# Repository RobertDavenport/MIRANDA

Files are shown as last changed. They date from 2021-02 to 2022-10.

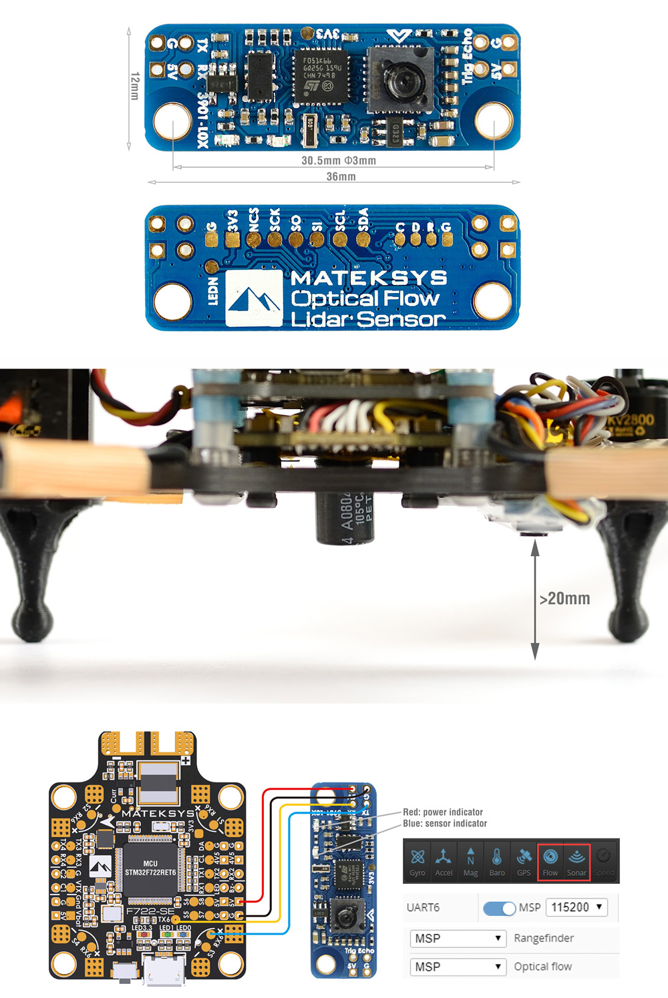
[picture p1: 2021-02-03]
project reference documents/parts/3901-L0X/3901-L0X.jpg

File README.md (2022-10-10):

# Robert-and-the-Davenports-Senior-Project

A set of wearable assistance devices which includes LIDAR sensors and one or more video cameras on glasses frames
and modular combinable haptic feedback devices. The device is capable of continually mapping a user’s environment in
relation to the user as they move and look around. The device also leverages artificial intelligence to take visual input
data from the onboard cameras to classify attributes. Processed data is relayed via audio and haptic cues to a user to allow
more situational awareness with the surrounding world. This set of devices is a novelty through the expanded
functionality of obstacle and object detection and recognition, in combination with haptic feedback.

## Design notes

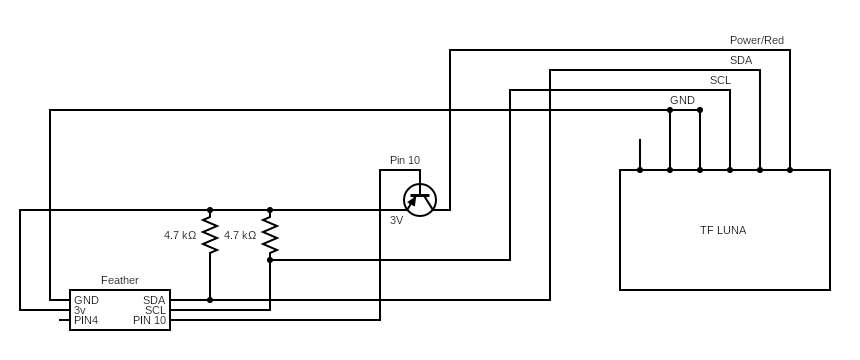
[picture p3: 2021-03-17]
project reference documents/FeatherTFLunaCircuitDiagram.png

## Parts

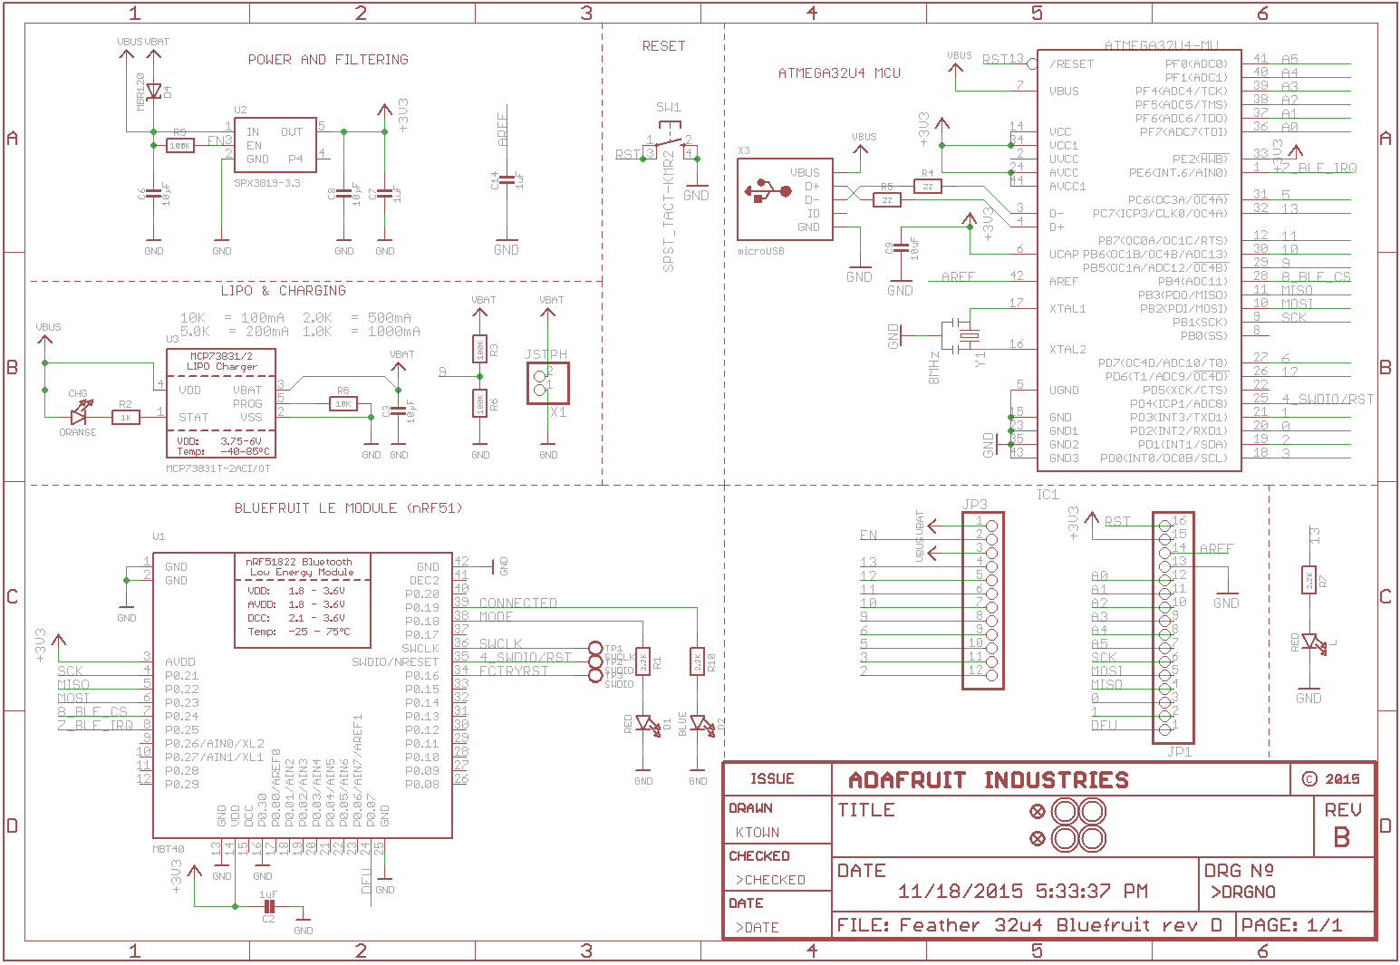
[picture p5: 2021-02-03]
project reference documents/parts/ADA2829/adafruit_products_schem.png

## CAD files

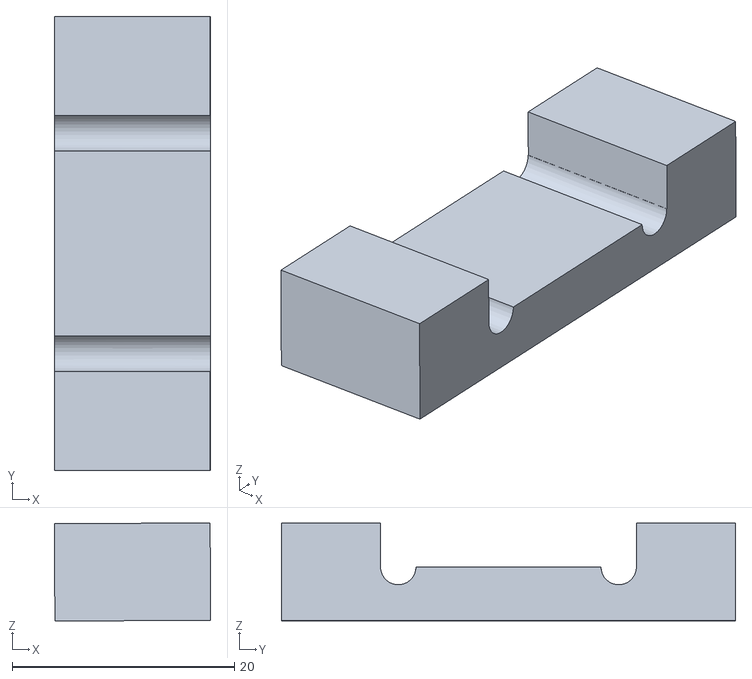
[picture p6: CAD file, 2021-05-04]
3d Printing Files/wristand pieces/wristband_pieces_-_motor_mount_x6 (1).stl
14.0 x 40.9 x 8.81

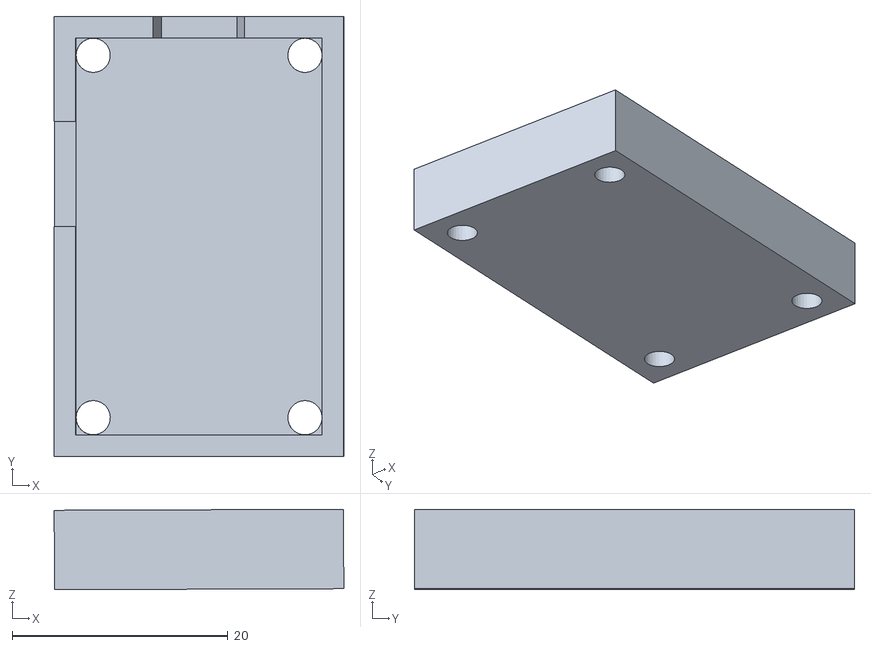
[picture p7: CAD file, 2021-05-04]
3d Printing Files/wristand pieces/wristband_pieces_v19_-_breakout_board_mount (1).stl
26.9 x 40.8 x 7.46

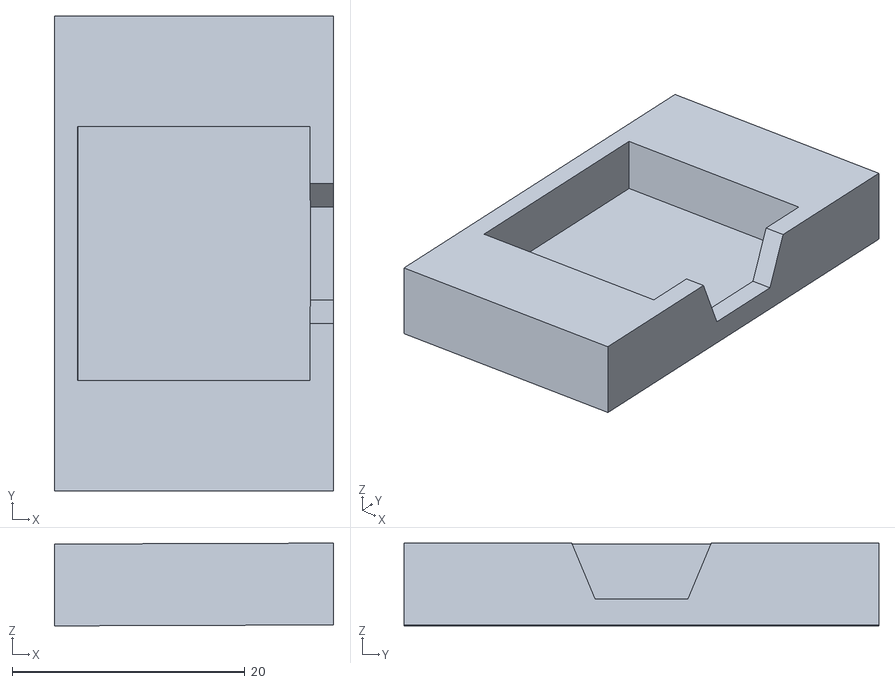
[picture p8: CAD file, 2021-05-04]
3d Printing Files/wristand pieces/wristband_pieces_-_switch_mount.stl
24.0 x 40.9 x 7.12

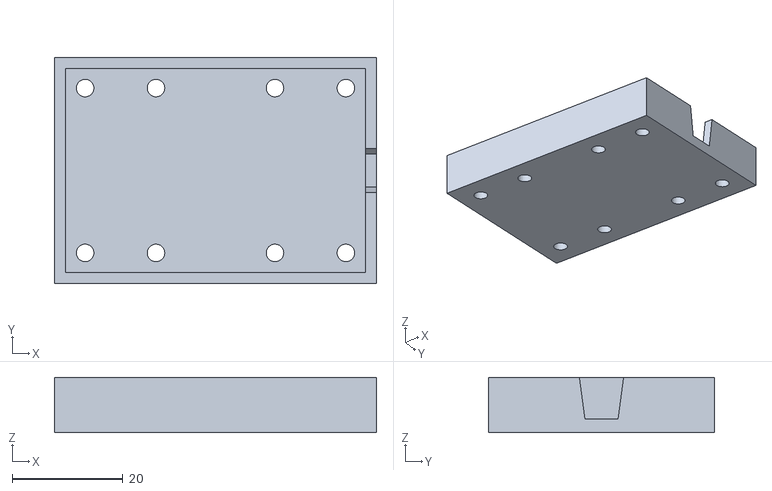
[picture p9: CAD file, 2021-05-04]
3d Printing Files/wristand pieces/wristband_pieces_v18_-_esp_battery_mount.stl
58.2 x 40.9 x 10.0

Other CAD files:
3d Printing Files/left bracket main.dwg
3d Printing Files/Base Mount/sensor plate.dwg
3d Printing Files/Base Mount/snap base.dwg
3d Printing Files/Base Mount/bracket base.dwg

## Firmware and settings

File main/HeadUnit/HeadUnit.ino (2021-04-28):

#include <math.h>
#include <I2Cdev.h>
#include <TFLI2C.h>
#include <MPU6050.h>
#include <Wire.h>
#include <Adafruit_MPU6050.h>
#include <Adafruit_Sensor.h>
#include <AsyncUDP.h>
#include <WiFi.h>
#include <String.h>
#include <sstream>

/* Determines if accelermeter will be used
   to account for movement when mapping the
   environment. */
#define MAP_AREA_WITHOUT_MOVEMENT

// Settings for area mapping structure
#define DPI 6
#define RADIAL_SEGMENTS 60
#define EMPTY -1

// Indices for sensor values
#define GYRO_X 0
#define GYRO_Y 1
#define GYRO_Z 2
#define ACCL_X 0
#define ACCL_Y 1
#define ACCL_Z 2

// Constants
#define ACCL_X_OFFSET 1.02
#define ACCL_Y_OFFSET 0.0005
#define ACCL_Z_OFFSET 0.155
#define NUM_LIDAR 3
#define NUM_HAPTICS 5
#define HAPTIC_CONTROL_LEVELS 8

/* Number of degrees in a cone that each haptic
   motor will be mapped to. */
#define DPH 15
#define MAX_DIST 100.0
#define MIN_DIST 0.0
#define MAX_READABLE_DIST 450.0
#define MIN_READABLE_DIST 0.0

// Math macros and definitions
#define PI 3.14159265
#define radians(d) (d*0.0174533)
#define degrees(r) (r*57.2958)
#define nearestK(n,k) (int)round(n/(float)k)
#define normalize(n) (((float)n-MIN_READABLE_DIST)/(MAX_READABLE_DIST - MIN_READABLE_DIST))*(MAX_DIST-MIN_DIST)+MIN_DIST;

// Data structures for area mapping and haptic control.
struct Sensors {
  float lidar[NUM_LIDAR];
  float accel[3];
  float gyro[3] = {0,0,0};
  bool lock = false;
};
struct AreaMap {
  float angles[RADIAL_SEGMENTS];
  float distances[RADIAL_SEGMENTS];
  bool lock = false;
};
struct HapticCommand {
  char hapticsArr[NUM_HAPTICS+2] = "hhhhh\0";
  char *haptics = hapticsArr;
  bool lock;
};

const uint8_t lidarAddresses[3] = {0x10, 0x20, 0x21};
const float lidarAngles[NUM_LIDAR] = {-15, 0, 15};
const float LIDAR_WIDTH = 30;
const float gyroOffset[3] = {0.0035025, 0.0025, 0.0019};
const float hapticOutputAngles[NUM_HAPTICS] = {-30, -15, 0, 15, 30};

float gyro[3];

// Definitions for haptic control intensity-to-distance mappings
const char HAPTIC_MAPPINGS_CHAR[HAPTIC_CONTROL_LEVELS] = {'a','b','c','d','e','f','g','h'};
const float HAPTIC_MAPPINGS_DIST[HAPTIC_CONTROL_LEVELS][2] = {{0,10},
                                                        {10,15},
                                                        {15,20},
                                                        {20,25},
                                                        {25,30},
                                                        {35,40},
                                                        {40,45},
                                                        {45,MAX_DIST+1}};

struct AreaMap areaMap; // Perm. struct for storing mapped area.
struct AreaMap tempMap; // Temp. struct for updating mapped area.
struct Sensors sensors; // Stores the rt-database of sensor values.
struct HapticCommand command; // Stores most recent haptic command.

// Wifi Connection Setup
const char *my_ssid = "esp32_ssid";
const char *password = "password";
int PORT = 1234;

unsigned long prevTime = 0;

Adafruit_MPU6050 mpu;
TFLI2C tfli2c;
AsyncUDP udp;

// Core-assigned task handles
TaskHandle_t AreaMappingTask;
TaskHandle_t ControlTask;

void setup() {
  Serial.begin(115200);  
  Wire.begin();
  mpu.begin();
  mpu.setGyroRange(MPU6050_RANGE_500_DEG);
  mpu.setFilterBandwidth(MPU6050_BAND_21_HZ);

  // Setup Wifi
  WiFi.mode(WIFI_AP);
  WiFi.softAP(my_ssid, password);

  // Control (networking and sensor reading) performed on core 0
  xTaskCreatePinnedToCore(
              control,        // Function
              "Control",      // Name
              16384,          // Stack size
              NULL,           // Parameters
              2,              // Priority
              &ControlTask,   // TaskHandle
              0);             // Core No.

  
  // Area mapping performed on core 1
  
  xTaskCreatePinnedToCore(
              areaMapping,      // Function
              "AreaMapping",    // Name
              16384,            // Stack size
              NULL,             // Parameters
              2,                // Priority
              &AreaMappingTask, // TaskHandle
              1);               // Core No.
  
  prevTime = millis();
  delay(1000);
}

void loop() {
}

void control( void * params ) {
  while(true) {

    /* Lock the sensor struct for copying */
    while(sensors.lock) { delay(1); }
    sensors.lock = true;
    Sensors temp = sensors;
    sensors.lock = false;

    /* Update the sensor struct */
    temp = readSensors(temp);

    /* Lock and replace the sensor struct */
    while(sensors.lock) { delay(1); }
    sensors.lock = true;
    sensors = temp;
    sensors.lock = false;

    /* Lock the haptic command for copying */
    while(command.lock) { delay(1); }
    command.lock = true;
    HapticCommand cmd = command;
    command.lock = false;

    Serial.println(cmd.haptics);
    udpBroadcast(cmd);

    String sout = String(temp.lidar[0]) + "\t" + String(temp.lidar[1]) + "\t" + String(temp.lidar[2]) + "\t" +
                        String(temp.gyro[0]) + "\t" + String(temp.gyro[1]) + "\t" + String(temp.gyro[2]) + "\t" +
                        "0\t0\t0\0";
    char buff[sout.length()];
    sout.toCharArray(buff, sout.length());
    char * bp = buff;
    udp.broadcastTo(bp,2005);
    delay(75);
  }
}

// Area Mapping
void areaMapping( void * params ) {

  while(true) {
    /* Wait for sensors data to be unlocked
      for use by this thread. */
    while(sensors.lock) { delay(1); }

    /* Temporarily lock the sensor data
      for use by this thread. The data
      is copied into a temporary struct
      because this function takes a long
      time to execute. */
    sensors.lock = true;
    struct Sensors tempSensors;
    tempSensors = sensors;
    sensors.lock = false;

    //tempSensors = normalizeDistances(tempSensors);
    updateMapDistances(tempSensors);
    updateHapticCommand(tempSensors);
    delay(300);
  }
}

/* ~~~~~~~ Misc functions ~~~~~~~ */
float getDeltaTime() {
  unsigned long nt = millis();
  float dt = (nt - prevTime) * 0.001;
  prevTime = nt;
  return dt;
}

/* ~~~~~~~ Area mapping functions ~~~~~~~ */
inline void angleMagitudeToComponent( float angle, float magnitude, float * coords ) {
  coords[0] = cosf(radians(angle)) * magnitude;
  coords[1] = sinf(radians(angle)) * magnitude;
}

inline void componentToAngleMagnitude( float x, float z, float * vec ) {
  vec[0] = degrees(atan2f(z,x));
  vec[1] = sqrtf((x * x)+(z * z));
  if(vec[0] < 0) { vec[0] += 360; }
}

// Update Mapping Distances
void updateMapDistances(Sensors s) {
  for(int i = 0; i < NUM_LIDAR; i++) {
    float angle = degrees(sensors.gyro[GYRO_Y]) + lidarAngles[i];
    if(angle > 360) {
      angle = angle - 360;
    }
    if(angle < 0) {
      angle = 360 + angle;
    }
    int index = nearestK(angle, DPI) % RADIAL_SEGMENTS;
    areaMap.angles[index] = fmodf(angle, 360);
    areaMap.distances[index] = s.lidar[i];
  }
}

// Normalize Distance data
Sensors normalizeDistances(Sensors s) {
  float relativeAngle = cosf(radians(s.gyro[GYRO_X]));
  for(int i = 0; i < NUM_LIDAR; i++) {
    s.lidar[i] = s.lidar[i] * relativeAngle;
  }
  return s;
}

#ifndef MAP_AREA_WITHOUT_MOVEMENT
// Update Area Mapping
void updateMapLocation(Sensors s) {
  
  // Return if there was no movement to update.
  if(s.accel[ACCL_X] == 0 && s.accel[ACCL_Z] == 0) { return; }

  for(int i = 0; i < RADIAL_SEGMENTS; i ++) {
    tempMap.angles[i] = i*DPI;
    tempMap.distances[i] = EMPTY;
  }

  for(int i = 0; i < RADIAL_SEGMENTS; i ++) {
    if(areaMap.distances[i] <= 0) { continue; }

    float angle = fmodf(areaMap.angles[i] + 180, 360);
    float dist = areaMap.distances[i];

    float componentVector[2];
    angleMagitudeToComponent(angle, dist, componentVector);
    componentVector[0] += s.accel[ACCL_Z];
    componentVector[0] += s.accel[ACCL_X];

    float amVector[2];
    componentToAngleMagnitude(componentVector[0], componentVector[2],
                              amVector);
    
    int index = ((int)round(amVector[0] / DPI)) % RADIAL_SEGMENTS;
    if(tempMap.distances[i] == EMPTY || (tempMap.distances[i] > amVector[1] && tempMap.distances[i] != EMPTY)) {
      tempMap.angles[index] = amVector[0];
      tempMap.distances[index] = amVector[1];
    }
  }

  for(int i = 0; i < RADIAL_SEGMENTS; i ++) {
    areaMap.angles[i] = tempMap.angles[i];
    areaMap.distances[i] = tempMap.distances[i];
  } 
  
  // Swap tempMap and areaMap w/ pointers, needs testing.
  /*
  struct AreaMap *temp;
  temp = &areaMap;
  areaMap = tempMap;
  tempMap = temp;
  */
}

// Normalize Accelermeter
Sensors normalizeAccelermeter(Sensors s) {
  float acclVector[2];
  componentToAngleMagnitude(s.accel[ACCL_X], s.accel[ACCL_Z], acclVector);
  acclVector[0] = fmodf(acclVector[0] + s.gyro[GYRO_X], 360);
  float acclComps[2];
  angleMagitudeToComponent(acclVector[0], acclVector[1], acclComps);
  s.accel[ACCL_X] = acclComps[0];
  s.accel[ACCL_Z] = acclComps[1];
  return s;
}
#endif

// Update Haptic Data
void updateHapticCommand(Sensors s) {
    char newCommand[NUM_HAPTICS];
    for(int i = 0; i < NUM_HAPTICS; i++)
      newCommand[i] = HAPTIC_MAPPINGS_CHAR[HAPTIC_CONTROL_LEVELS-1];
    for(int i = 0; i < NUM_HAPTICS; i++) {
      float angle = degrees(sensors.gyro[GYRO_Y]) + hapticOutputAngles[i];
      if(angle > 360) {
        angle = angle - 360;
      }
      if(angle < 0) {
        angle = 360 + angle;
      }
      float dist = areaDistanceQuery(angle, DPH);
      char mapping = HAPTIC_MAPPINGS_CHAR[HAPTIC_CONTROL_LEVELS-1];
      if(dist == 0) { newCommand[i] = mapping; }
      else {
        for(int j = 0; j < HAPTIC_CONTROL_LEVELS; j++){
          if(dist >= HAPTIC_MAPPINGS_DIST[j][0] && dist < HAPTIC_MAPPINGS_DIST[j][1]) {
            mapping = HAPTIC_MAPPINGS_CHAR[j];
            break;
          }
        }
        
        newCommand[i] = mapping;
      }
    }
    /* Wait for command data to be unlocked
      for use by this thread. */
    while(command.lock) { delay(1); }
    command.lock = true;
    for(int i = 0; i < NUM_HAPTICS; i++)
      command.hapticsArr[i] = newCommand[i];
    command.lock = false;
}

// Get Area Distance
float areaDistanceQuery(float angle, float coneWidth) {
  float distance = MAX_DIST + 1;
  int indexStart = angle/DPI - (coneWidth/2)/DPI;
  int indexEnd = angle/DPI + (coneWidth/2)/DPI;
  for(; indexStart <= indexEnd; indexStart++){
    int index = indexStart % RADIAL_SEGMENTS;
    if(index < 0) { index = RADIAL_SEGMENTS + index; }
    if(areaMap.distances[index] <= 0) { continue; }
    if(distance > areaMap.distances[index]) { distance = areaMap.distances[index]; }
  }
  if(distance == MAX_DIST + 1) { return 0; }
  return distance;
}

/* ~~~~~~~ Sensor reading functions ~~~~~~~ */
void getGyroAngles(float * gyro, sensors_event_t gevent, float deltaTime) {
  auto updateAngle = [&](float ang, float offset, float upd, float dt) -> float {
    ang = ang + offset + upd * dt;
    if(ang > 2*PI)
      ang = ang - 2*PI;
    if(ang < 0)
      ang = 2*PI - ang;
    return ang;
  };
  gyro[2] = updateAngle(gyro[2], gyroOffset[2], gevent.gyro.x, deltaTime);
  gyro[1] = updateAngle(gyro[1], gyroOffset[1], gevent.gyro.y, deltaTime);
  gyro[0] = updateAngle(gyro[0], gyroOffset[0], gevent.gyro.z, deltaTime);
}

/* ~~~~~~~ Control functions ~~~~~~~ */
Sensors readSensors(Sensors old) {
  sensors_event_t a, g, temp;
  mpu.getEvent(&a, &g, &temp);
  float dt = getDeltaTime();
  getGyroAngles(old.gyro, g, dt);
  readLidarArray(old.lidar);
  return old;
}

// Read from Lidar Array
void readLidarArray(float * lidar) {
  for(int i = 0; i<3; i++){
    int16_t tempDistance;
    tfli2c.getData(tempDistance, lidarAddresses[i]);
    //Serial.println(tempDistance);
    lidar[i] = normalize(tempDistance);
  }
}

// Broadcast haptic data via UDP
void udpBroadcast(HapticCommand cmd) {
  //for(int i = 0; i < NUM_HAPTICS; i++)
  //  Serial.print(cmd.haptics[i]);
  //Serial.println();
  udp.broadcastTo(cmd.haptics,PORT);
}

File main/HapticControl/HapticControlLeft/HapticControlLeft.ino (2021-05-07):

//#include <TimeProfiler.h>
#include <WiFi.h>
#include <AsyncUDP.h>
#include <analogWrite.h>

const char * ssid = "esp32_ssid";
const char * password = "password";

char intensity[8] = {'a', 'b', 'c', 'd', 'e', 'f', 'g', 'h'};
int intensity_values[8] = {255, 255, 255, 175, 175, 155, 0, 0};
int pins[3] = {14, 12, 13};
int port = 1234;
char * sensorMappings;

AsyncUDP udp;


void setup() {
  for(int i = 0; i<3; i++){
    pinMode(pins[i], OUTPUT);
  }
  Serial.begin(115200);

  WiFi.mode(WIFI_STA); // Make this the client (the server is WIFI_AP)
  WiFi.begin(ssid, password);
  delay(100);
  Serial.print("Connecting...");
  // Display a period every 0.5 s to show the user something is happening.
  while (WiFi.waitForConnectResult() != WL_CONNECTED) { 
    Serial.print(".");
    delay(500);
  }
}

void loop() {
  if(udp.listen(port)) {
    udp.onPacket([](AsyncUDPPacket packet) {
      Serial.print("Received data: ");
      Serial.write(packet.data(), packet.length());
      Serial.println();
      sensorMappings = (char * )packet.data();
      Serial.println(sensorMappings);
      int vals[3] = {0,0,0};
      for(int i = 0; i<3; i++){
          char c = sensorMappings[i];
          int j = 0;
          for(j = 0; j < 8; j++){
          if(c == intensity[j])
              break; 
          }
          vals[i] = intensity_values[j];
      }
      for(int i = 0; i<3; i++){
        analogWrite(pins[i], vals[i]);
      } 
    });
  }   
}

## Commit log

2021-02-03 Spec/Data Sheets Added
    Reference documents for each of our current components have been added to a "project reference documents" folder with specific folders for each individual component. Please add any other reference in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
2021-02-03 Added haptic motor test code
    Added an arduino file to test a haptic motor using the Feather 32u4 board.
2021-02-23 Create tflunaDistanceAndFeedback.ino
    Added the testing file we were using to combine the sensor with the vibration motor. Meant to commit last night.
2021-02-24 TFLI2C link added to README
    added the link to the library used for the tfluna sensor. Mostly committing to check formatting I forget how it works
2021-02-24 Performance Testing for Sensor
    Added a performance testing file to test the average time it takes to get data from the sensor, perform calculations for the haptic feedback, and output the feedback..
    Also added a small update to the Distance and Feedback file to correct for the inverted feedback response
2021-02-24 add dwg files for 3d model
    [bracket base.dwg, left bracket main.dwg, sensor plate.dwg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]
2021-03-17 Create FeatherTFLunaCircuitDiagram.png
    Added the circuit diagram created for reference between the feather and the TF Luna
2021-03-17 Update encryption.ino
    Additional code implementing encryption in arduino ID. Currently this process is too heavy for our needs and as we aren't sending sensitive data, this approach will not be implemented. WIP Code is included for reference later if we find use.
2021-03-17 Added haptic wristband control file
    This file contains the Arduino script for controlling the wristband, which is currently reading input values from serial rather than Bluetooth.
2021-03-17 Added head unit file
    This file contains the Arduino program that will read distances from a single TF Luna sensor and output the normalized value over serial to the connected wristband.
2021-03-17 Fixed grammatical issues and added comments.
    [HeadUnit.ino]
2021-03-23 Created Arduino libraries for interacting with the distance sensor array and accelerometer/gyroscope
2021-03-25 Update tflunaDistanceAndFeedback.ino
    Added one time setup for I2C Addressing for the TF Luna sensors
2021-03-29 adding 3d files for wristband components
    - controller_platform_v2 is the latest version of the mounting platform for the ESP boards
    - wristband_pieces_v1 is the wristband link the mounting platform will mount to
    (these may change if I can think of a better way of mating the platform and the band link)
    [controller_platform_v2.stl, wristband_pieces_v1.stl]
2021-03-29 Update tflunaDistanceAndFeedback.ino
    Code Cleanup and Variable name changes after sensor addressing completed
2021-04-06 Area mapping test
    Area mapping test to be used with simulated or real sensors.
2021-04-07 Added Function to read from lidar array
    Added a function in HeadUnit to read from the array of lidar sensors and update an array of distances
2021-04-07 Added I2C address setup file
    Created separate file to change I2C addresses on TF Luna sensors
2021-04-07 3D model for the haptic motor mount
    [motor mount v1.stl]
2021-04-07 Added LidarArray Library WIP
    Added the lidar array library I've worked on, but it is not functioning fully
2021-04-16 Added Gyroscope to Head Unit Code
    WIP added being able to read from the gyroscope to the Head unit code reading from the TF Luna sensors
2021-04-17 Left and Right Haptic motor files
    Left and Right Haptic motor files that will parse the broadcasted mappings.
2021-04-17 moved haptic files into separate folders and changed analogwrite to ledcwrite
    moved haptic files into separate folders. Required by arduinio ide since they are seperate sketches. Also changed analogwrite to ledcWrite as the esp32 does not have a definition for analogwrite :(
2021-04-18 Added reading from gyroscope
    Added code to read from the gyroscope on the accelerometer/gyroscope sensor
    Also fixed an issue where the initial readings didnt work when powering on the controller without uploading code
    [HeadUnit.ino]
2021-04-18 Added a temporary mapping to test the headunit
    temporary mapping which will be replaced by area mapping functionality.
    [HeadUnit.ino]
2021-04-18 Update HapticControlLeft.ino
    added analogWrite library for esp32. Added corrent pins for new board. minor code changes.
2021-04-21 haptic wristband design change
    Changes to haptic motor to work around new design of 3 motors
2021-04-23 Changed sensorMapping to Char array
    Changed sensorMapping to Char array and other relevant code to work with Alex's headunit broadcast.
2021-04-27 Fixed and implemented area mapping
    Fixed the issues with area mapping and implemented it for use. The functionality is tested and working. Also fixed an issue with the storage, mutability, and retrieval of the haptic command character array.
    [HeadUnit.ino]
2021-04-28 Fixed issue with right wrist undefined behavior
    [HapticControlRight.ino]
2021-04-28 Added sensor data output to port 2005
2021-04-30 Fixed segmentation issue in haptic control of right wrist
    [HapticControlRight.ino]
2021-05-01 Wristband Port Packet fix
    Fixed issue where wristbands were picking up packets from other ports. Re-added broadcast on port 2005 to headunit.
    [HapticControlLeft.ino, HapticControlRight.ino, HeadUnit.ino]
2021-05-04 Removed old Arduino libraries
2021-05-04 Added Arduino libraries
    Added necessary Arduino library dependencies.
2021-05-04 Added newest wristband 3d models
    [controller_platform_v2.stl, motor mount v1.stl, wristband_pieces_-_motor_mount_x6 (1).stl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]
2021-05-05 Updated Haptic Pins to match current wiring
